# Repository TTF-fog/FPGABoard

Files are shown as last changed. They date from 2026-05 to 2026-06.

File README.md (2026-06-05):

# S3GA
an FPGA board based on the ICE40UP5K and the ESP32S3-Mini (module). 

Allows for wireless functionality (maybe even programming?) using the ESP32S3-M and IO using the iCE

## Why?
- i wasn't able to find any boards that integrated wireless functionality with the ICE40UP5K, so i decided to make one!

# Setup
- I recommend getting the QFN packages assembled, but you can smd solder them if you want
- for code flashing, read # Usage below
# Usage
- the S3 can be developed for using Arduino / ESP-IDF and programmed with the respective tools
    - the iCE can be developed with [iCEStorm](https://github.com/YosysHQ/icestorm) or [iCEcube2](https://www.latticesemi.com/en/Products/DesignSoftwareAndIP/FPGAandLDS/iCEcube2) and programmed using the bitstream generated by the [Diamond Programmer](https://www.latticesemi.com/en/Products/DesignSoftwareAndIP/ProgrammingAndConfigurationSw/Programmer).
     To flash use [SPIFFS](https://docs.espressif.com/projects/esp-idf/en/stable/esp32/api-reference/storage/spiffs.html) to save a file under the name "stream" for the generated bitstream, and then use the [flash code](Firmware/mcu-flash)

# Sublinks
- [BOM](BOM.csv)
- [Gerbers](Hardware/production_files/production_files/GERBER-FPGABoard.zip)
- [Zine](Zine.pdf)
- [Schematic PDF](Hardware/design_files/Schematic.pdf)
# Pinout

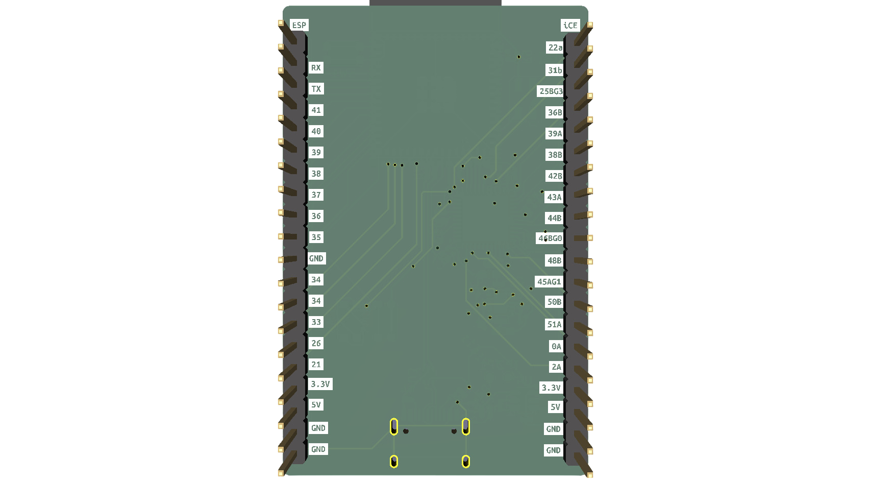
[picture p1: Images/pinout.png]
Pinout


# Images

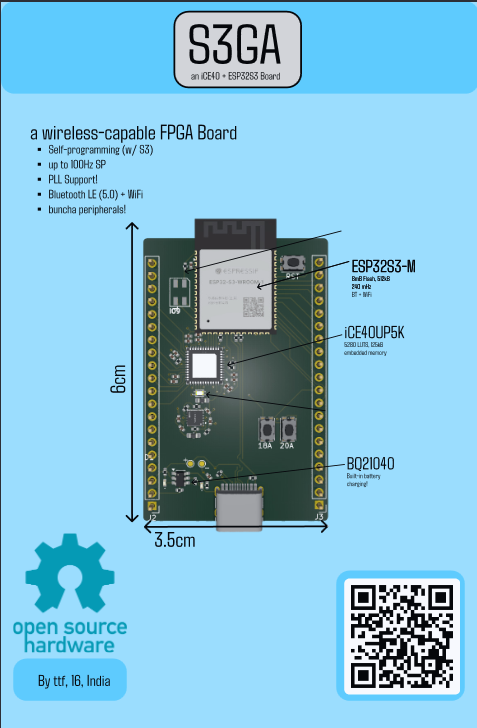
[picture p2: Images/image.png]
Zine

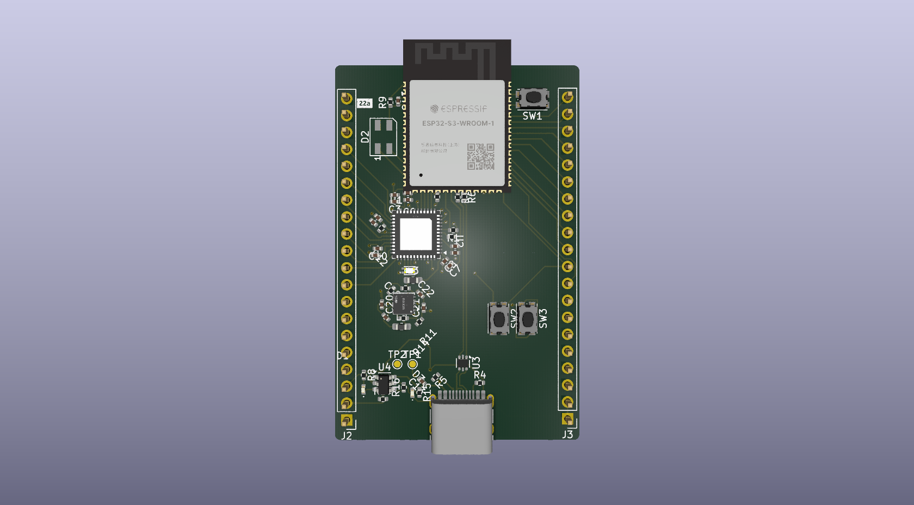
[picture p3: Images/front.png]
Board




note: if the images don't load, you can see them at [images](Images)

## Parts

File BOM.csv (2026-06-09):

Comment | Designator | Footprint | LCSC | Quantity | Link | Unit Price (USD) | Total Cost (USD)
100 | R10 | R_0402_1005Metric | C25076 | 1 | https://www.lcsc.com/product-detail/C25076.html | 0.0006 | 0.0006
100k | R13 | R_0402_1005Metric | C25741 | 1 | https://www.lcsc.com/product-detail/C25741.html | 0.0019 | 0.0019
100n | C19,C21 | C_0402_1005Metric | C1525 | 2 | https://www.lcsc.com/product-detail/C1525.html | 0.0025 | 0.005
100nF | C16,C2,C3,C6,C7,C9 | C_0402_1005Metric | C1525 | 6 | https://www.lcsc.com/product-detail/C1525.html | 0.0025 | 0.015
10K | R1,R17,R2,R3 | R_0402_1005Metric | C25744 | 4 | https://www.lcsc.com/product-detail/C25744.html | 0.0019 | 0.0076
10uF | C11 | C_0402_1005Metric | C15525 | 1 | https://www.lcsc.com/product-detail/C15525.html | 0.0115 | 0.0115
1K | R15,R16,R8 | R_0402_1005Metric | C11702 | 3 | https://www.lcsc.com/product-detail/C11702.html | 0.0019 | 0.0057
1uF | C13 | C_0402_1005Metric | C52923 | 1 | https://www.lcsc.com/product-detail/C52923.html | 0.003 | 0.003
20 | R9 | R_0402_1005Metric | C2004 | 1 | https://www.lcsc.com/product-detail/C2004.html | 0.0006 | 0.0006
22k | R14 | R_0402_1005Metric | C25768 | 1 | https://www.lcsc.com/product-detail/C25768.html | 0.0019 | 0.0019
22u | C20,C22 | C_0402_1005Metric | C385994 | 2 | https://www.lcsc.com/product-detail/C385994.html | 0.008 | 0.016
33 | R6,R7 | R_0402_1005Metric | C25105 | 2 | https://www.lcsc.com/product-detail/C25105.html | 0.0006 | 0.0012
4.7uF | C1,C10,C15,C4,C5,C8 | C_0402_1005Metric | C23733 | 6 | https://www.lcsc.com/product-detail/C23733.html | 0.0044 | 0.0264
5.1K | R4,R5 | R_0402_1005Metric | C25905 | 2 | https://www.lcsc.com/product-detail/C25905.html | 0.0019 | 0.0038
51k | R11,R12 | R_0402_1005Metric | C25794 | 2 | https://www.lcsc.com/product-detail/C25794.html | 0.0019 | 0.0038
AOTA-B201610S3R3-101-T | L2,L3 | L_0603_1608Metric_Pad1.05x0.95mm_HandSolder | C42411119 | 2 | https://www.lcsc.com/product-detail/C42411119.html | 0.28 | 0.54
BQ21040DBV | U4 | SOT-23-6 | C78978 | 1 | https://www.lcsc.com/product-detail/C78978.html | 0.2207 | 0.2207
ESP32-S3-MINI-1 | U2 | ESP32-S2-MINI-1 | C2913206 | 1 | https://www.lcsc.com/product-detail/C2913206.html | 3.314 | 3.314
ICE40UP5K-SG48ITR | U1 | QFN-48-1EP_7x7mm_P0.5mm_EP5.6x5.6mm | C2678152 | 1 | https://www.lcsc.com/product-detail/C2678152.html | 5.8766 | 5.8766
LED | D1,D3 | LED_0402_1005Metric | C71911 | 2 | https://www.lcsc.com/product-detail/C71911.html | 0.022 | 0.044
RT8075ZQW | U6 | WDFN-10_L3.0-W3.0-P0.50-BL-EP | C250416 | 1 | https://www.lcsc.com/product-detail/C250416.html | 0.3761 | 0.3761
SW_Push | SW1,SW2,SW3 | SW_Push_1P1T_NO_CK_KMR2 | C72443 | 3 | https://www.lcsc.com/product-detail/C72443.html | 0.347 | 1.041
TJ-S1608SW6TDSLCCYRGB-A5 | U5 | LED-ARRAY-SMD_4P-L1.6-W0.8-BL-FD | C5356078 | 1 | https://www.lcsc.com/product-detail/C5356078.html | 0.0741 | 0.15
USBLC6-2P6 | U3 | SOT-666 | C53059594 | 1 | https://www.lcsc.com/product-detail/C53059594.html | 0.15 | 0.15
USB_C_Receptacle_USB2.0_14P | J1 | USB_C_Receptacle_HRO_TYPE-C-31-M-12 | C165948 | 1 | https://www.lcsc.com/product-detail/C165948.html | 0.0973 | 0.0973
Conn_01x20_Pin | J3 | PinHeader_1x20_P2.54mm_Vertical |  | 1 | DNP
Conn_01x20_Pin | J2 | PinHeader_1x20_P2.54mm_Vertical |  | 1 | DNP
TestPoint | TP1 | TestPoint_Pad_D1.0mm |  | 1 | DNP
TestPoint | TP2 | TestPoint_Pad_D1.0mm |  | 1 | DNP
SK6812MINI-E | D2 | LED_SK6812MINI_PLCC4_3.5x3.5mm_P1.75mm |  | 1 | DNP
PCB | N/A | N/A | N/A | 5 |  | 7 | 7
 |  |  |  |  |  | GRAND TOTAL | 18.9137 | (usd)

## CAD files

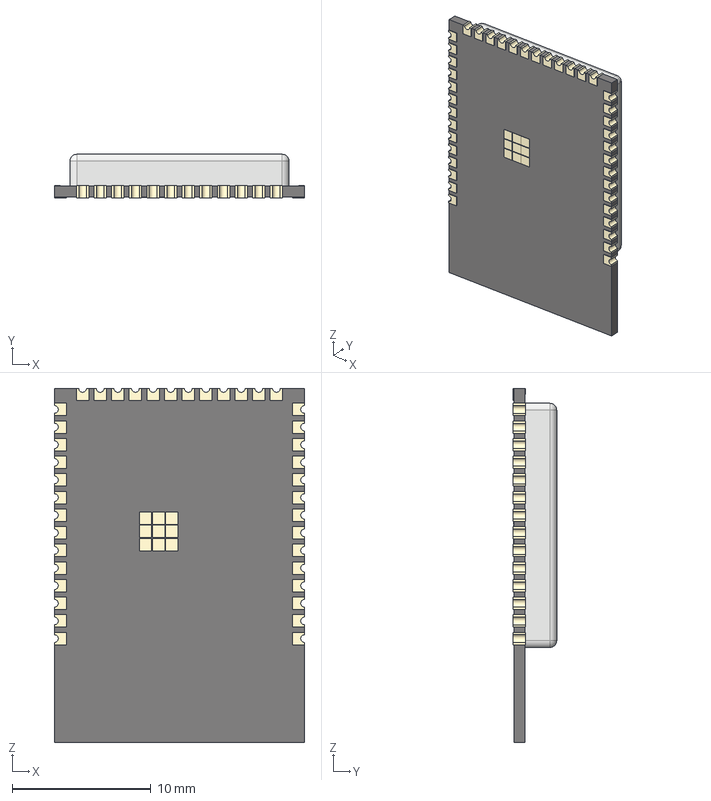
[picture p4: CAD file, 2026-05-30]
hardware/design_files/models/ESP32-S3-WROOM.step
18.0 x 3.16 x 25.5 mm
ESP-S3-WROOM_via x 26
ESP32-S3-WROOM_shell
ESP32-S3-WROOM_body
ESP-S3-WROOM_via v3(镜像) x 14

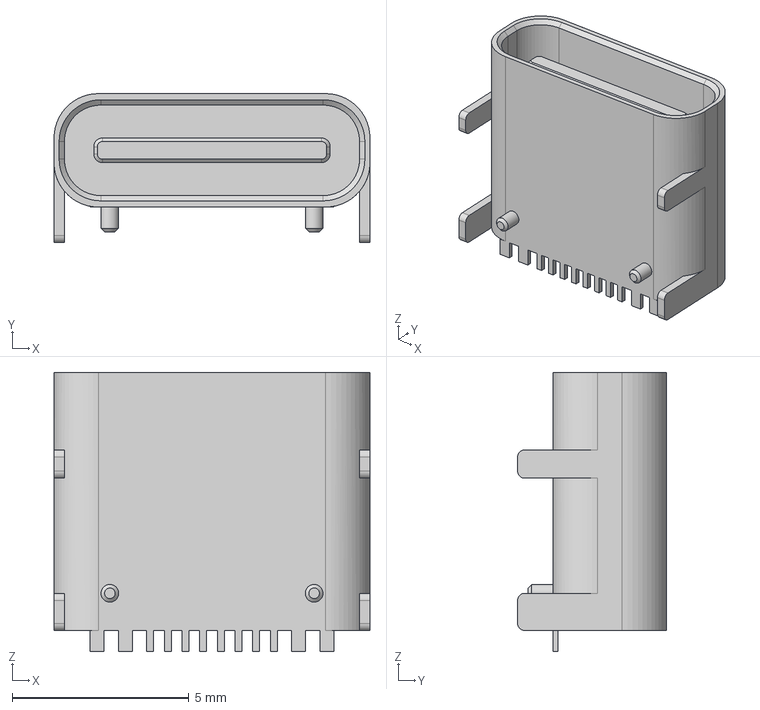
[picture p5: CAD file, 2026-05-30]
hardware/design_files/models/HRO TYPE-C-31-M-12.step
8.94 x 4.21 x 7.90 mm

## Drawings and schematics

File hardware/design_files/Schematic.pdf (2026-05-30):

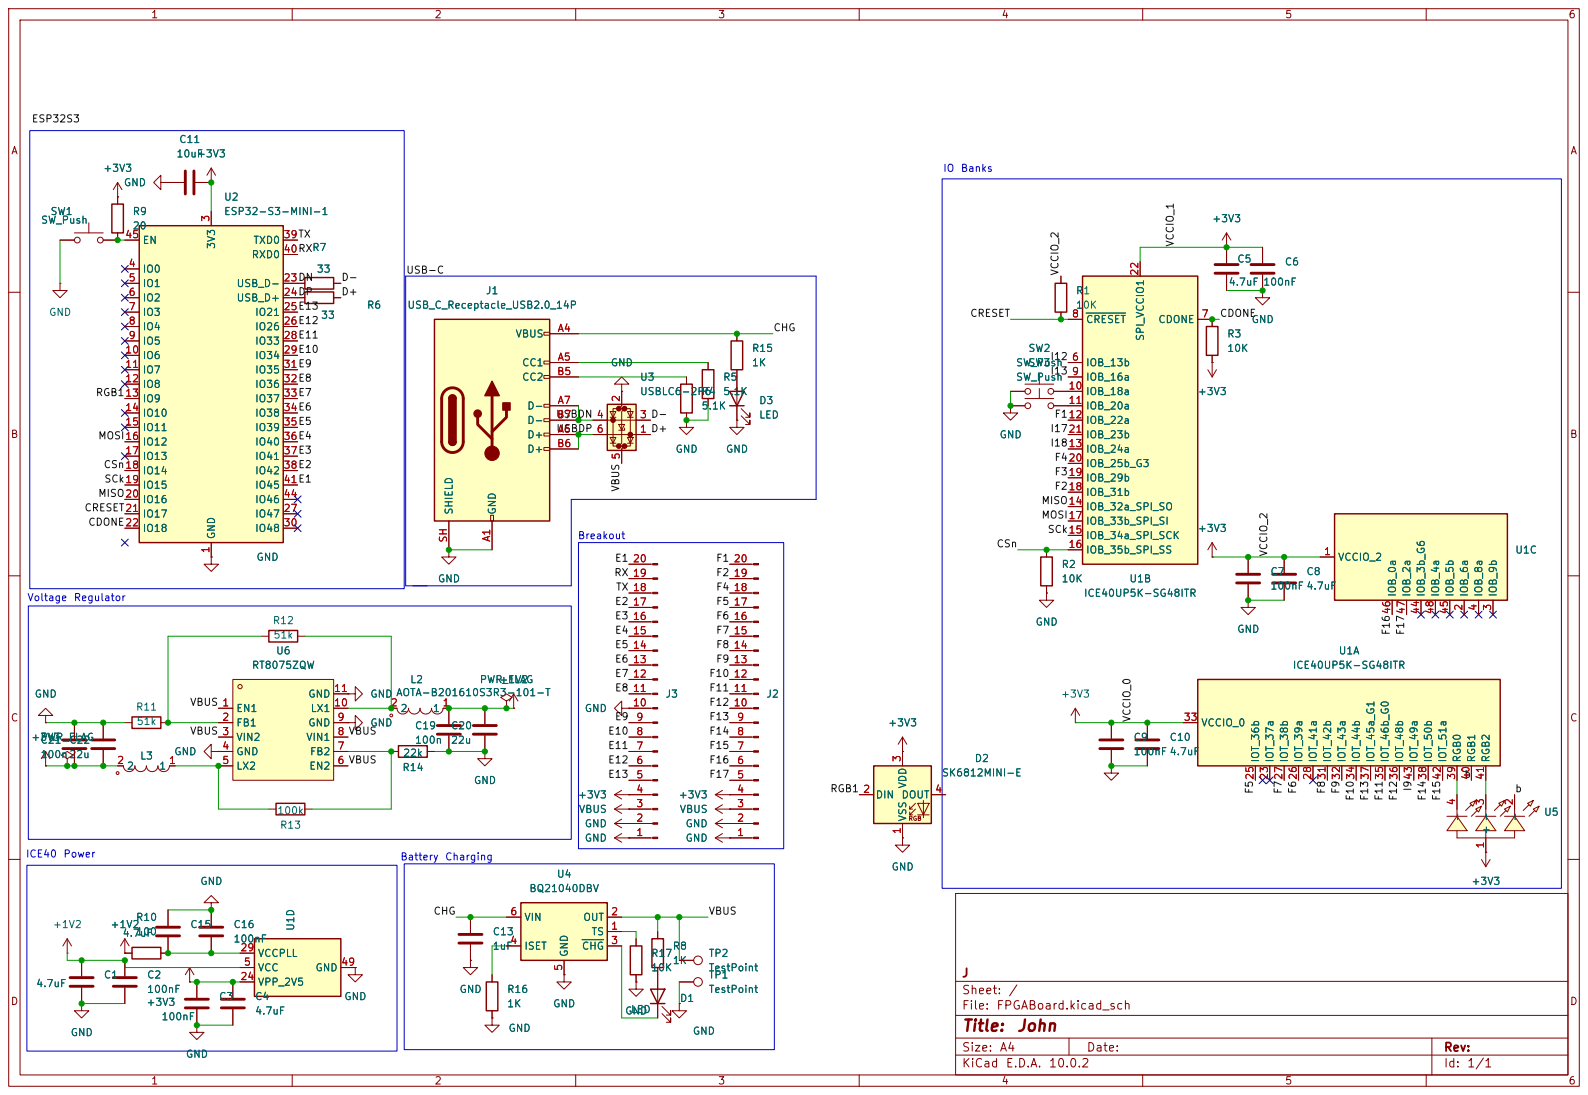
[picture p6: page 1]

Size: A4 | Rev:
KiCad E.D.A. 10.0.2 | Id: 1/1

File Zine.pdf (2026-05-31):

# S3GA

## an iCE40 + ESP32S3 Board

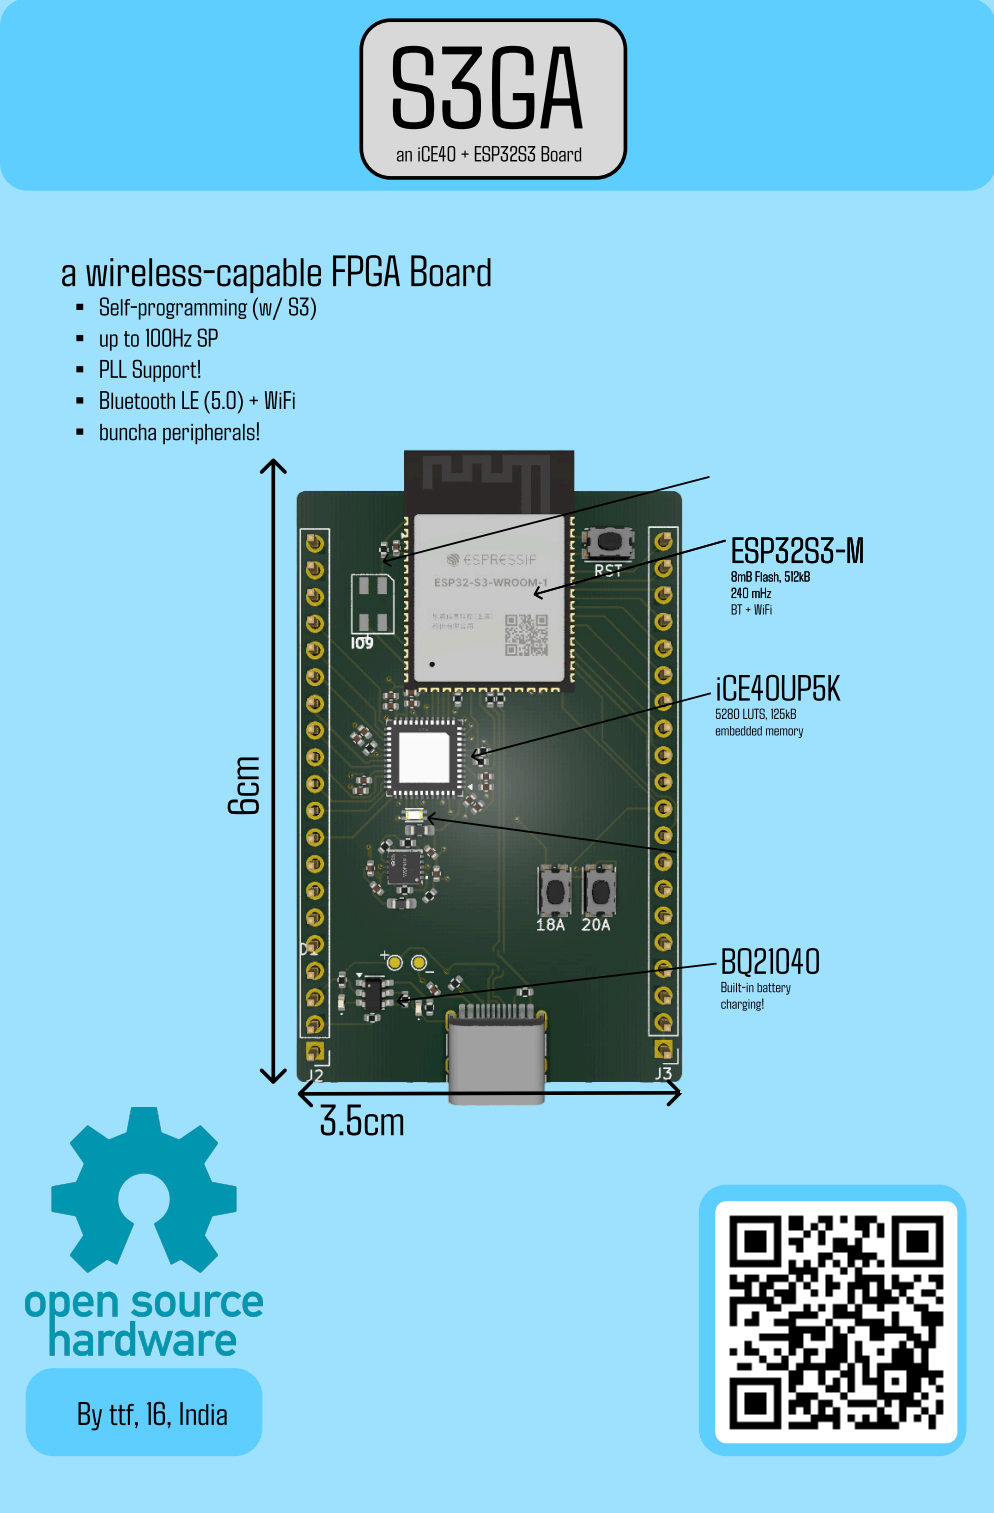
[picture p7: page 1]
iCE40UP5K; 5280 LUTS, 125kB; embedded memory; 8mB Flash, 512kB 240 mHz 240 mHz; BT + WiFi; ESP32S3-M

a wireless-capable FPGA Board
buncha peripherals!6cm

Self-programming (w/ S3)
PLL Support!
Bluetooth LE (5.0) + WiFi

Built-in battery
charging!

By ttf, 16, India

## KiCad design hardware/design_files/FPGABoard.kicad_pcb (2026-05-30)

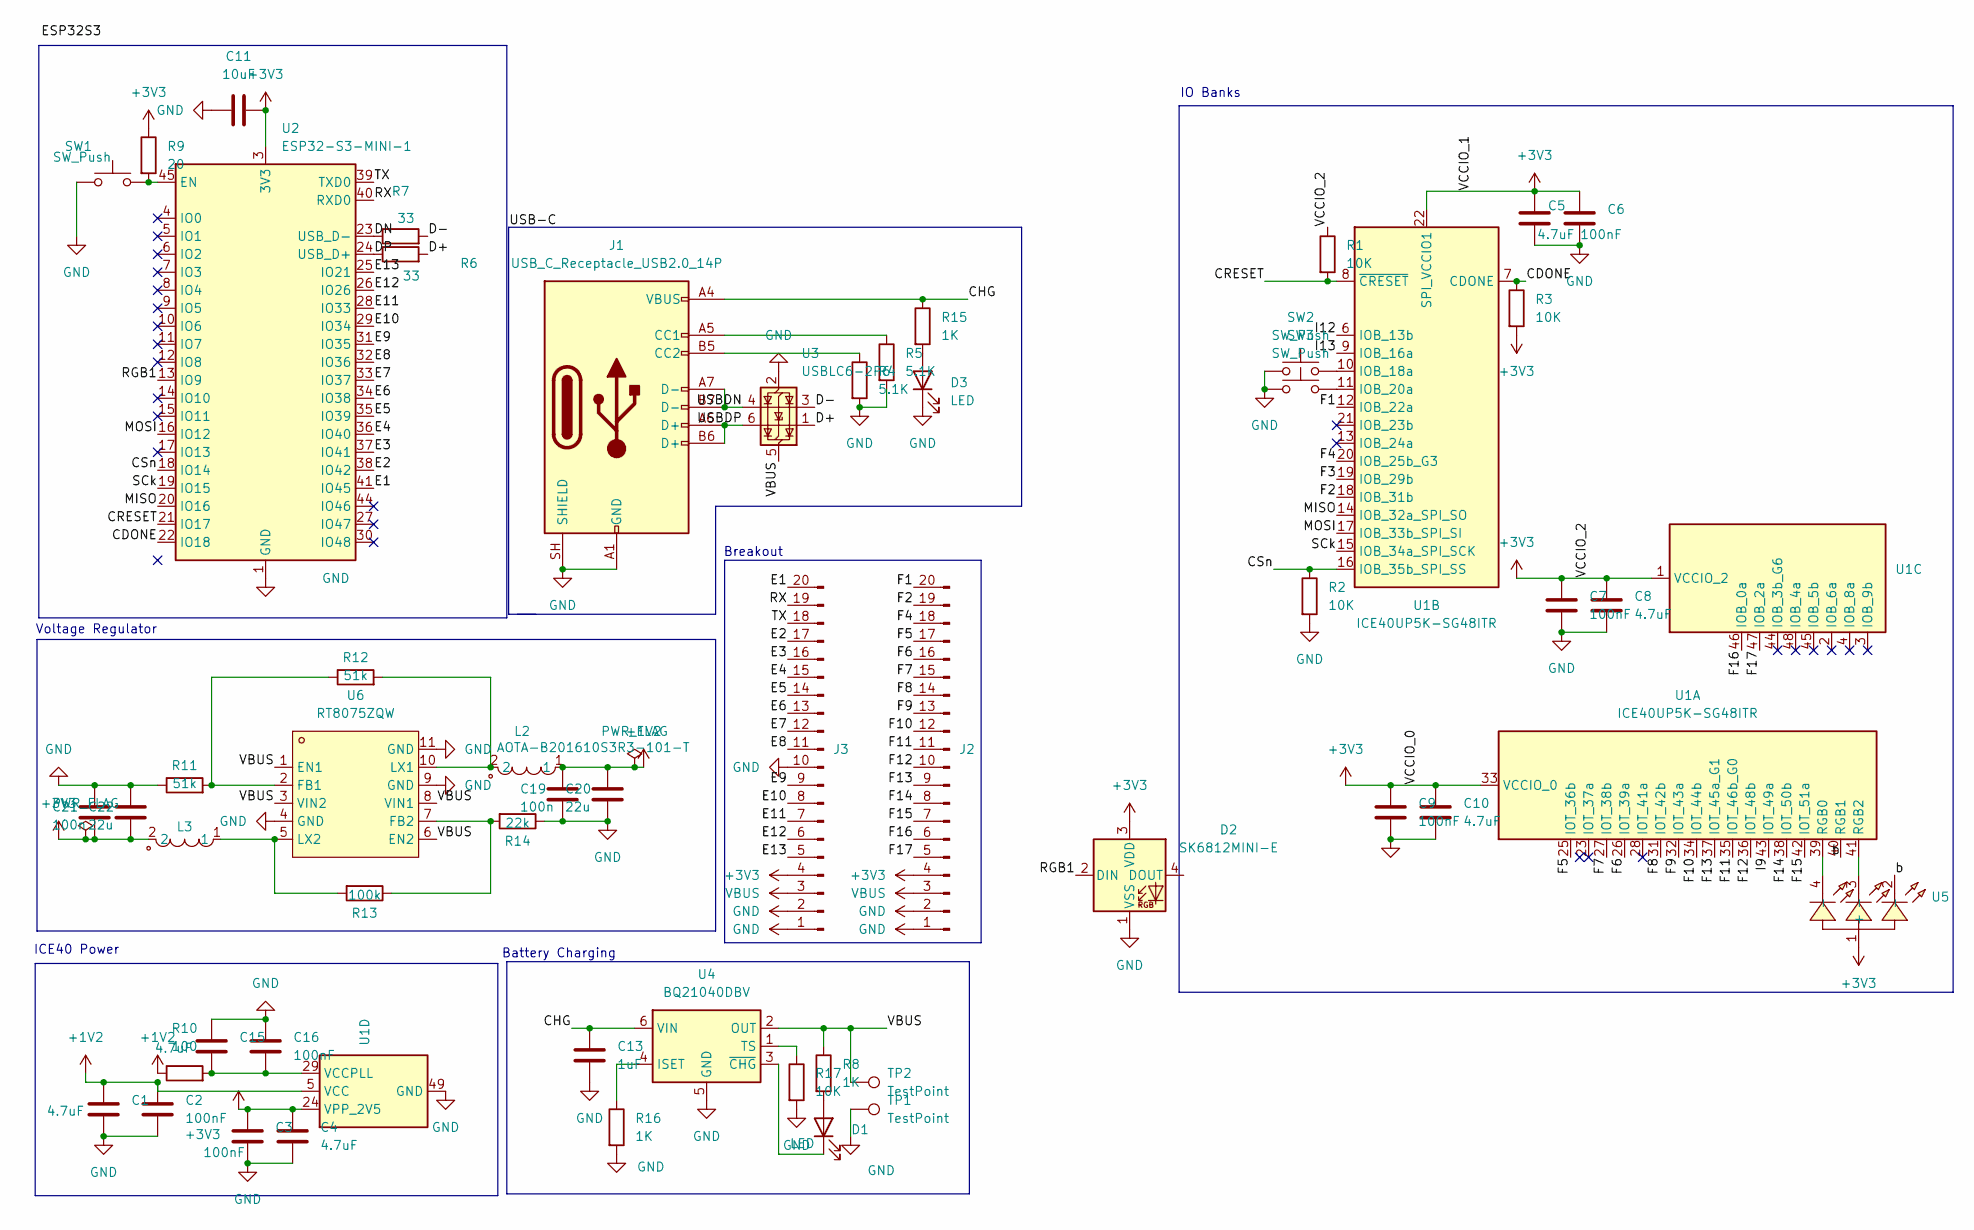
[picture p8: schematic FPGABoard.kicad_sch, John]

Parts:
C1, C4, C5, C8, C10, C15: 4.7uF; C_0402_1005Metric
C2, C3, C6, C7, C9, C16: 100nF; C_0402_1005Metric
C11: 10uF; C_0402_1005Metric
C13: 1uF; C_0402_1005Metric
C19, C21: 100n; C_0402_1005Metric
C20, C22: 22u; C_0402_1005Metric
D1, D3: LED; LED_0402_1005Metric
D2: SK6812MINI-E; LED_SK6812MINI-E_3.2x2.8mm_P1.5mm_ReverseMount
J1: USB_C_Receptacle_USB2.0_14P; USB_C_Receptacle_HRO_TYPE-C-31-M-12
J2, J3: Conn_01x20_Pin; PinHeader_1x20_P2.54mm_Vertical
L2, L3: AOTA-B201610S3R3-101-T; L_0603_1608Metric_Pad1.05x0.95mm_HandSolder; LCSC Part C42411119
R1, R2, R3, R17: 10K; R_0402_1005Metric
R4, R5: 5.1K; R_0402_1005Metric
R6, R7: 33; R_0402_1005Metric
R8, R15, R16: 1K; R_0402_1005Metric
R9: 20; R_0402_1005Metric
R10: 100; R_0402_1005Metric
R11, R12: 51k; R_0402_1005Metric
R13: 100k; R_0402_1005Metric
R14: 22k; R_0402_1005Metric
SW1, SW2, SW3: SW_Push; SW_Push_1P1T_NO_CK_KMR2
TP1, TP2: TestPoint; TestPoint_Pad_D1.0mm
U1: ICE40UP5K-SG48ITR; QFN-48-1EP_7x7mm_P0.5mm_EP5.6x5.6mm
U2: ESP32-S3-MINI-1; ESP32-S2-MINI-1
U3: USBLC6-2P6; SOT-666
U4: BQ21040DBV; SOT-23-6
U5: TJ-S1608SW6TDSLCCYRGB-A5; LED-ARRAY-SMD_4P-L1.6-W0.8-BL-FD; MPN TJ-S1608SW6TDSLCCYRGB-A5; LCSC Part C5356078
U6: RT8075ZQW; WDFN-10_L3.0-W3.0-P0.50-BL-EP; LCSC Part C250416

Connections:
+1V2: C1.1, C2.1, C19.1, C20.1, L2.1, R10.1, U1.5 (VCC), U1.30 (VCC)
+3V3: C3.1, C4.1, C5.1, C6.1, C7.1, C8.1, C9.1, C10.1, C11.2, C21.2, C22.2, D2.3 (VDD), J2.4, J3.4, L3.2, R1.1, R3.2, R9.1, U1.1 (VCCIO_2), U1.22 (SPI_VCCIO1), U1.24 (VPP_2V5), U1.33 (VCCIO_0), U2.3 (3V3), U5.1 (+)
/CDONE: R3.1, U1.7 (CDONE), U2.22 (IO18)
/CHG: C13.1, J1.A4 (VBUS), J1.A9 (VBUS), J1.B4 (VBUS), J1.B9 (VBUS), R15.1, U4.6 (VIN)
/CRESET: R1.2, U1.8 (~CRESET), U2.21 (IO17)
/CSn: R2.1, U1.16 (IOB_35b_SPI_SS), U2.18 (IO14)
/D+: R6.2, U3.1 (I/O1)
/D-: R7.2, U3.3 (I/O2)
/DN: R7.1, U2.23 (USB_D-)
/DP: R6.1, U2.24 (USB_D+)
/E1: J3.20, U2.41 (IO45)
/E2: J3.17, U2.38 (IO42)
/E3: J3.16, U2.37 (IO41)
/E4: J3.15, U2.36 (IO40)
/E5: J3.14, U2.35 (IO39)
/E6: J3.13, U2.34 (IO38)
/E7: J3.12, U2.33 (IO37)
/E8: J3.11, U2.32 (IO36)
/E9: J3.9, U2.31 (IO35)
/E10: J3.8, U2.29 (IO34)
/E11: J3.7, U2.28 (IO33)
/E12: J3.6, U2.26 (IO26)
/E13: J3.5, U2.25 (IO21)
/F1: J2.20, U1.12 (IOB_22a)
/F2: J2.19, U1.18 (IOB_31b)
/F3: U1.19 (IOB_29b)
/F4: J2.18, U1.20 (IOB_25b_G3)
/F5: J2.17, U1.25 (IOT_36b)
/F6: J2.16, U1.26 (IOT_39a)
/F7: J2.15, U1.27 (IOT_38b)
/F8: J2.14, U1.31 (IOT_42b)
/F9: J2.13, U1.32 (IOT_43a)
/F10: J2.12, U1.34 (IOT_44b)
/F11: J2.11, U1.35 (IOT_46b_G0)
/F12: J2.10, U1.36 (IOT_48b)
/F13: J2.9, U1.37 (IOT_45a_G1)
/F14: J2.8, U1.38 (IOT_50b)
/F15: J2.7, U1.42 (IOT_51a)
/F16: J2.6, U1.46 (IOB_0a)
/F17: J2.5, U1.47 (IOB_2a)
/I9: U1.43 (IOT_49a)
/I12: U1.6 (IOB_13b)
/I13: U1.9 (IOB_16a)
/I17: U1.21 (IOB_23b)
/I18: U1.13 (IOB_24a)
/MISO: U1.14 (IOB_32a_SPI_SO), U2.20 (IO16)
/MOSI: U1.17 (IOB_33b_SPI_SI), U2.16 (IO12)
/RGB1: D2.2 (DIN), U2.13 (IO9)
/RX: J3.19, U2.40 (RXD0)
/SCk: U1.15 (IOB_34a_SPI_SCK), U2.19 (IO15)
/TX: J3.18, U2.39 (TXD0)
/USBDN: J1.A7 (D-), J1.B7 (D-), U3.4 (I/O2)
/USBDP: J1.A6 (D+), J1.B6 (D+), U3.6 (I/O1)
/b: U1.40 (RGB1), U5.2 (-)
GND: C1.2, C2.2, C3.2, C4.2, C5.2, C6.2, C7.2, C8.2, C9.2, C10.2, C11.1, C13.2, C15.1, C16.1, C19.2, C20.2, C21.1, C22.1, D2.1 (VSS), D3.1 (K), J1.A1 (GND), J1.A12 (GND), J1.B1 (GND), J1.B12 (GND), J1.SH (SHIELD), J2.1, J2.2, J3.1, J3.2, J3.10, R2.2, R4.2, R5.2, R11.1, R14.1, R16.2, R17.2, SW1.1, SW2.1, SW3.1, TP1.1 (1_1), U1.49 (GND), U2.1 (GND), U2.2 (GND), U2.42 (GND), U2.43 (GND), U2.46 (GND), U2.47 (GND), U2.48 (GND), U2.49 (GND), U2.50 (GND), U2.51 (GND), U2.52 (GND), U2.53 (GND), U2.54 (GND), U2.55 (GND), U2.56 (GND), U2.57 (GND), U2.58 (GND), U2.59 (GND), U2.60 (GND), U2.61 (GND), U2.62 (GND), U2.63 (GND), U2.64 (GND), U2.65 (GND), U3.2 (GND), U4.5 (GND), U6.4 (GND), U6.9 (GND), U6.11 (GND)
unnamed: D1.2 (A), R8.2
unnamed: D1.1 (K), U4.3 (~CHG)
unnamed: D3.2 (A), R15.2
unnamed: J1.A5 (CC1), R5.1
unnamed: J1.B5 (CC2), R4.1
unnamed: U1.39 (RGB0), U5.4 (-)
unnamed: U1.41 (RGB2), U5.3 (-)
unnamed: SW2.2, U1.10 (IOB_18a)
unnamed: SW3.2, U1.11 (IOB_20a)
unnamed: C15.2, C16.2, R10.2, U1.29 (VCCPLL)
unnamed: R9.2, SW1.2, U2.45 (EN)
unnamed: R16.1, U4.4 (ISET)
unnamed: R17.1, U4.1 (TS)
unnamed: R11.2, R12.1, U6.2 (FB1)
unnamed: R13.1, R14.2, U6.7 (FB2)
unnamed: L2.2, R12.2, U6.10 (LX1)
unnamed: L3.1, R13.2, U6.5 (LX2)
VBUS: J2.3, J3.3, R8.1, TP2.1 (1_1), U3.5 (VBUS), U4.2 (OUT), U6.1 (EN1), U6.3 (VIN2), U6.6 (EN2), U6.8 (VIN1)

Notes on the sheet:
IO Banks
Battery Charging
Breakout
ICE40 Power
Voltage Regulator

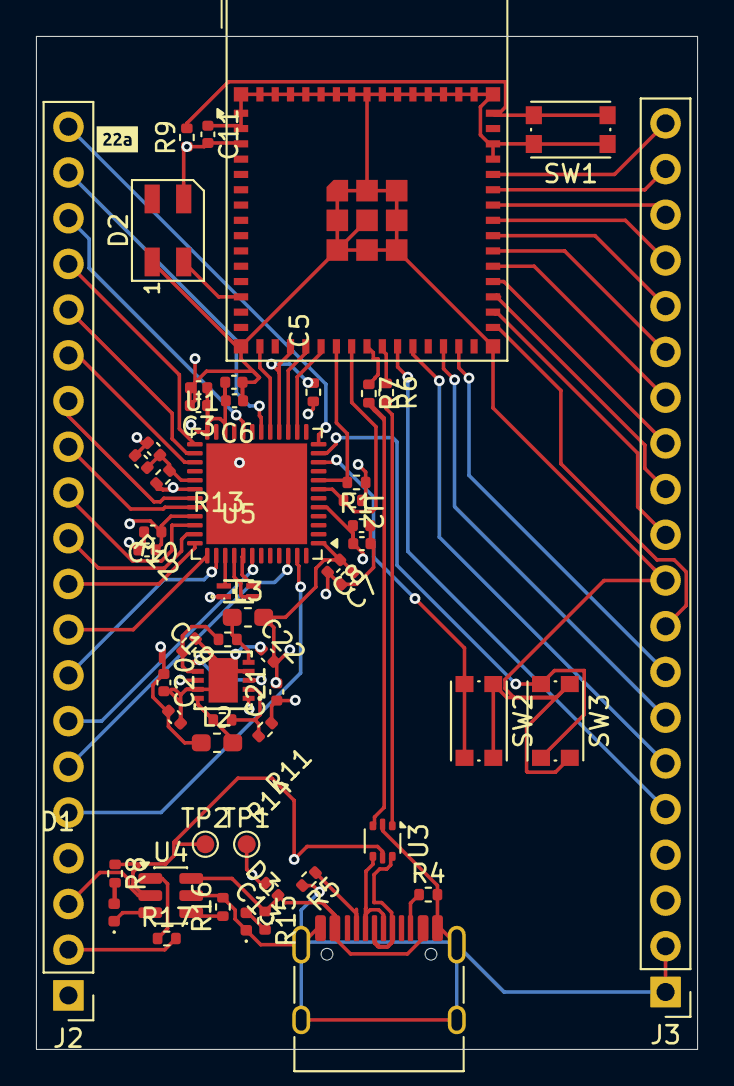
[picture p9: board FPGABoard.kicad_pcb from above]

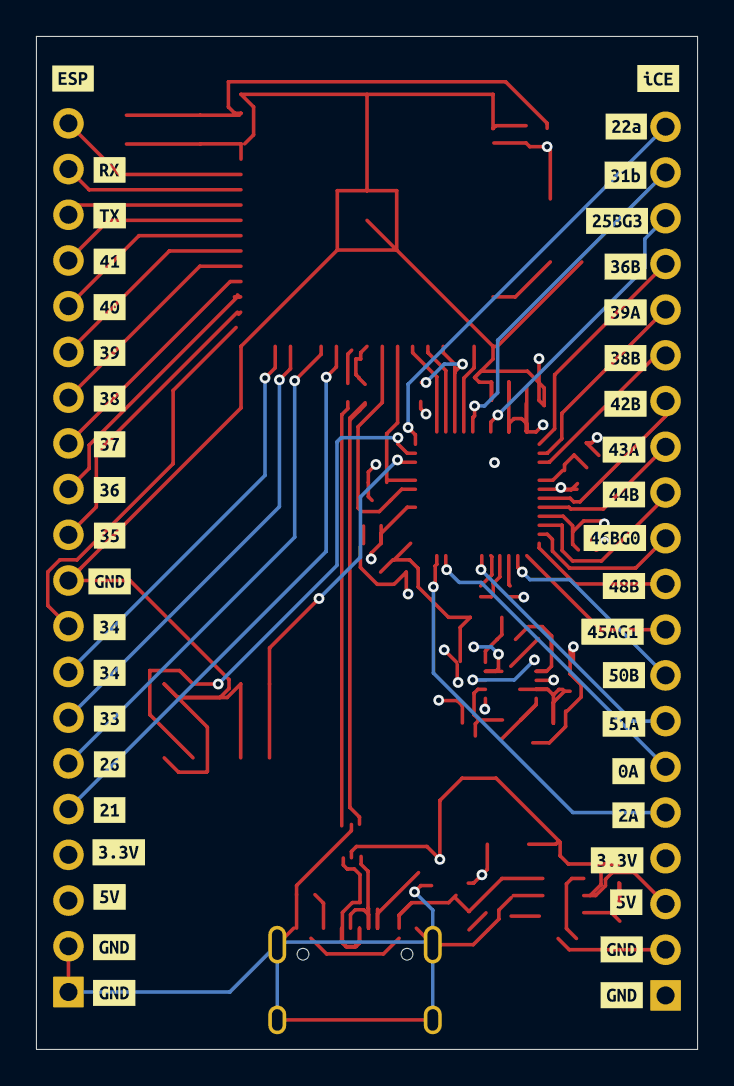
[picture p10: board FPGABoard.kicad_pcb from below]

Board: 4 copper layers, 36.7 x 56.3 mm, 96 parts (41 on the bottom side), 67 nets.

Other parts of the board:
kibuzzard-6A1AFA27, kibuzzard-6A1AFA27#2: G***; kibuzzard-6A1AFA27
kibuzzard-6A1AFA79, kibuzzard-6A1AFA79#2: G***; kibuzzard-6A1AFA79
kibuzzard-6A1AFA94, kibuzzard-6A1AFA94#2, kibuzzard-6A1AFA94#3, kibuzzard-6A1AFA94#4: G***; kibuzzard-6A1AFA94
kibuzzard-6A1AFB9A: G***; kibuzzard-6A1AFB9A
kibuzzard-6A1AFBC0: G***; kibuzzard-6A1AFBC0
kibuzzard-6A1AFC0F: G***; kibuzzard-6A1AFC0F
kibuzzard-6A1AFC22, kibuzzard-6A1AFC22#2: G***; kibuzzard-6A1AFC22
kibuzzard-6A1AFC53: G***; kibuzzard-6A1AFC53
kibuzzard-6A1AFC58: G***; kibuzzard-6A1AFC58
kibuzzard-6A1AFD1A: G***; kibuzzard-6A1AFD1A
kibuzzard-6A1AFD12: G***; kibuzzard-6A1AFD12
kibuzzard-6A1AFD34: G***; kibuzzard-6A1AFD34
kibuzzard-6A1AFD40: G***; kibuzzard-6A1AFD40
kibuzzard-6A1AFD49: G***; kibuzzard-6A1AFD49
kibuzzard-6A1AFD53: G***; kibuzzard-6A1AFD53
kibuzzard-6A1AFD64: G***; kibuzzard-6A1AFD64
kibuzzard-6A1AFD94: G***; kibuzzard-6A1AFD94
kibuzzard-6A1AFEE8: G***; kibuzzard-6A1AFEE8
kibuzzard-6A1AFEEE: G***; kibuzzard-6A1AFEEE
kibuzzard-6A1AFF00: G***; kibuzzard-6A1AFF00
kibuzzard-6A1AFF0B: G***; kibuzzard-6A1AFF0B
kibuzzard-6A1AFF2B: G***; kibuzzard-6A1AFF2B
kibuzzard-6A1AFF6D: G***; kibuzzard-6A1AFF6D
kibuzzard-6A1AFF8C: G***; kibuzzard-6A1AFF8C
kibuzzard-6A1AFF40: G***; kibuzzard-6A1AFF40
kibuzzard-6A1AFF78: G***; kibuzzard-6A1AFF78
kibuzzard-6A1AFFA5: G***; kibuzzard-6A1AFFA5
kibuzzard-6A1AFFB7: G***; kibuzzard-6A1AFFB7
kibuzzard-6A1B014D: G***; kibuzzard-6A1B014D
kibuzzard-6A1B016E: G***; kibuzzard-6A1B016E
kibuzzard-6A1B018E: G***; kibuzzard-6A1B018E
kibuzzard-6A1B0130: G***; kibuzzard-6A1B0130
kibuzzard-6A1B0165: G***; kibuzzard-6A1B0165
kibuzzard-6A1B0180: G***; kibuzzard-6A1B0180
kibuzzard-6A1B0204: G***; kibuzzard-6A1B0204
kibuzzard-6A1B0228: G***; kibuzzard-6A1B0228

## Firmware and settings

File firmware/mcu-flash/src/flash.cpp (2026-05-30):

#include "Arduino.h"
#include "SPI.h"
#include "SPIFFS.h"
#define CS 14
#define CRESET_B 17
void delayNanoseconds(int ns) {
    delay(ns/1000);
}
void setup() {
    while (!Serial.begin(9600)){}
    SPIClass flash;
    pinMode(CS, OUTPUT);
    pinMode(CRESET_B, OUTPUT);
    flash.begin(15, 16, 12, CS);
    SPIFFS.begin();
    File bitstream = SPIFFS.open("stream", "r");
    digitalWrite(CS, LOW);
    digitalWrite(CRESET_B, LOW);
    Serial.println("FPGA reset"); //note: check if logging could caause timing issues
    delayMicroseconds(200);
    digitalWrite(CRESET_B, HIGH);
    Serial.println("SPI peripheral mode");
    delayMicroseconds(1200);
    SPISettings settings = SPISettings(4000000, MSBFIRST, SPI_MODE0);{};
    flash.beginTransaction(settings);
    flash.transferBytes(bitstream.readBytes());
    flash.endTransaction();
    Serial.println("transferred");
    pinMode(18, INPUT);
    while (digitalRead(18) == LOW) {Serial.println("error while programming");}
    char dummy[48];
    flash.beginTransaction(settings);
    flash.transferBytes(dummy,0,sizeof(dummy));
    flash.endTransaction();
    Serial.println("done programming!");
}
void loop(){}

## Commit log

2026-06-01 add links to bom
    [BOM.csv]
2026-06-06 update bom
    [BOM-FPGABoard.csv, ESP32-S3-WROOM.step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]
